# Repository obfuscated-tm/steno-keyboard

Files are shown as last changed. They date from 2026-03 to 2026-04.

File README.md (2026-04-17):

# Owen's Steno Keyboard Mk. 1
The PCB, firmware, casing, as well as the keycaps are all made by myself, from scratch.  
The PCB schematics and design, CAD step files, and firmware are stored within their retrospective folders.

## Screenshots
steno-full  

* On the bottom-most row, the keys on both sides that are furthest away from the center are the number keys.  
* The two double length keys in the middle (one on each side) is the '*' key.
* The other keys follow standard steno layout.
  
steno-keyless  

steno-pcb  

* The decision to have each switch have their own GPIO port is just for ease of assembly and that there was no reason not to do so.  

## Bill of Materials 
- 4 M3 x 12mm screw
- 4 M3 x 0.5mm nut
- 25 Mechanical switches (Cherry MX)
- 1 Raspberry Pi Pico
- 1 PCB
- 1 Micro USB cable
- 3 3D printed 2.5u Steno keycaps (OR 2u standard keycaps)
- 22 3D printed 1.5u Steno keycaps (OR 1u standard keycaps)
- 1 3D printed enclosure (Optional, 3 parts)  
~210g of filament total for 3D printed parts

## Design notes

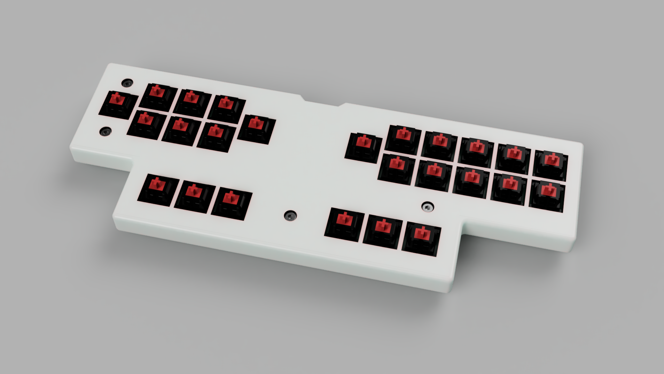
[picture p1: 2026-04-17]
CAD-files/render/steno-keyless.PNG

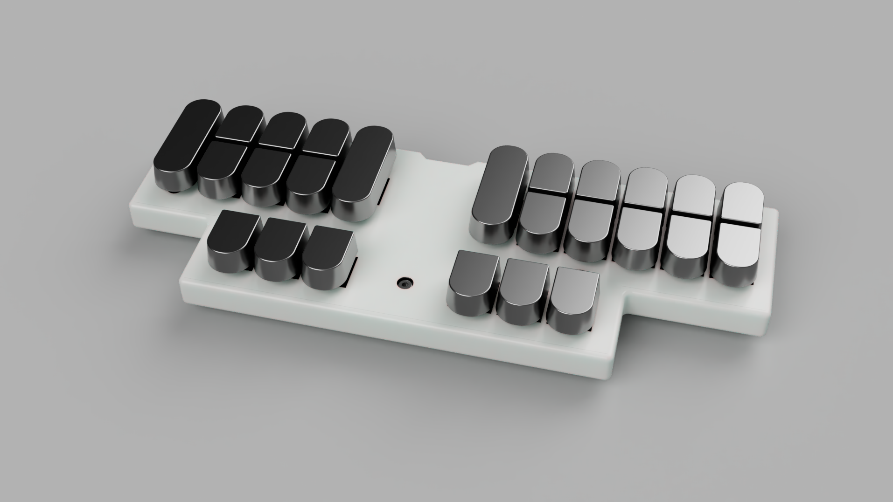
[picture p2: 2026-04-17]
CAD-files/render/steno-full.PNG

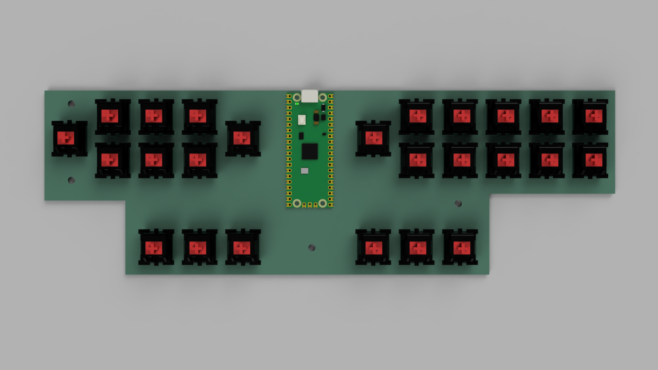
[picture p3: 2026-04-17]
CAD-files/render/steno-pcb.PNG

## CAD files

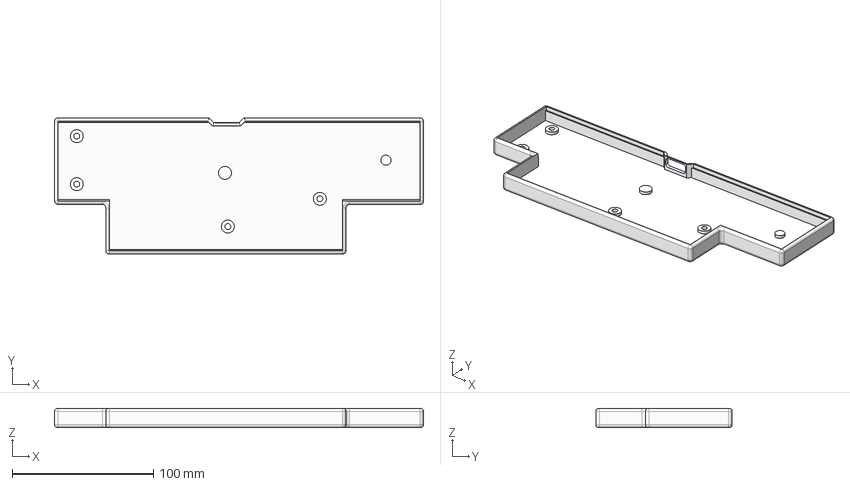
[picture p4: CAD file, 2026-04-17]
CAD-files/housing-body.step
261.4 x 96.6 x 13.5 mm

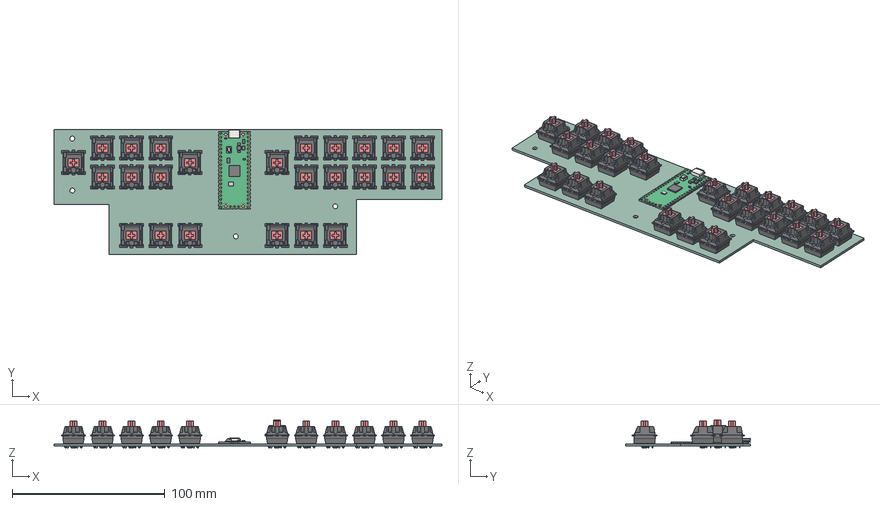
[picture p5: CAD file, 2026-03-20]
steno-pcb/steno-keyboard.step
254.0 x 82.1 x 18.2 mm
RaspberryPi_Pico_Module_KiCad
steno-keyboard_PCB

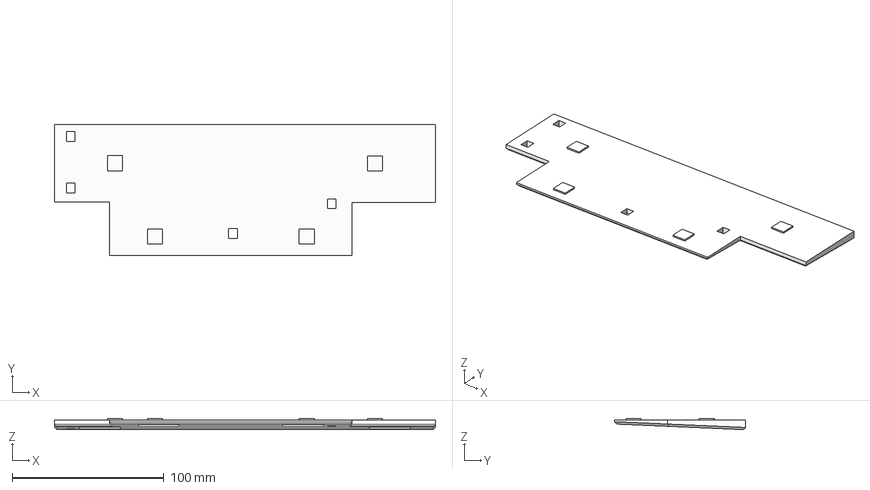
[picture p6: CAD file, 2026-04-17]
CAD-files/housing-base.step
251.4 x 86.6 x 7.44 mm

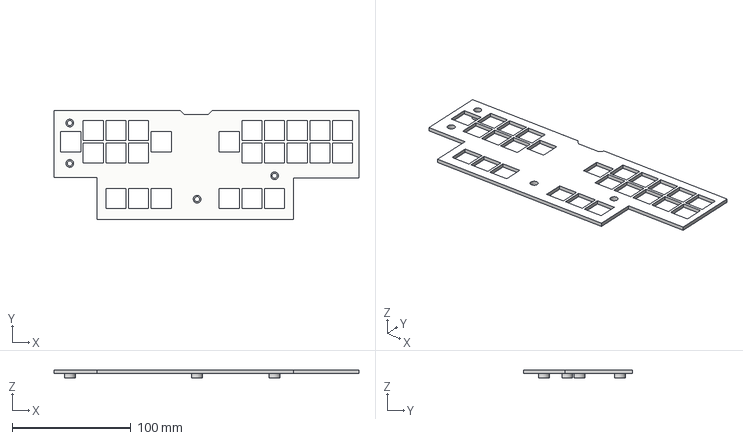
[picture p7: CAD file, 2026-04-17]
CAD-files/top-plate.step
256.4 x 91.6 x 6.83 mm

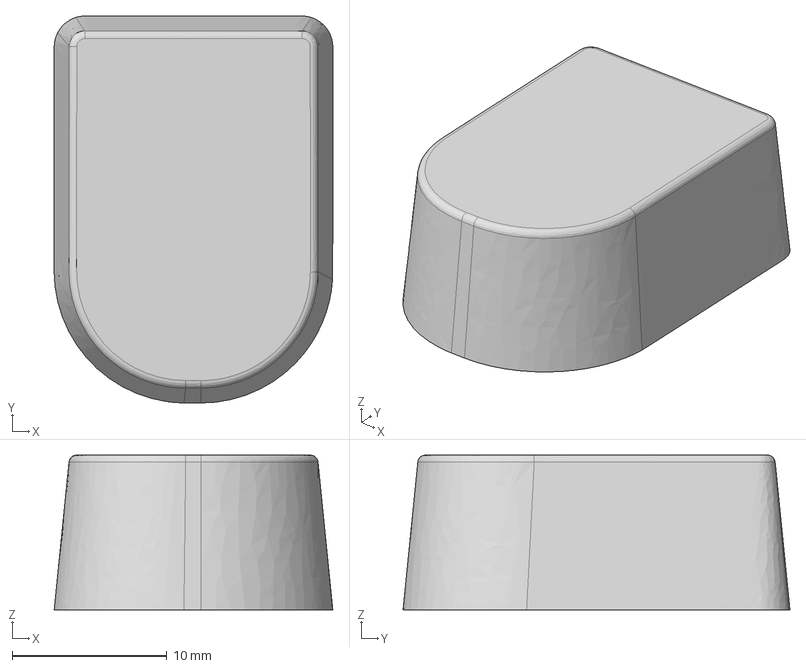
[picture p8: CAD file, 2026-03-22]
CAD-files/steno-keycap-1.5u.step
18.0 x 25.0 x 10.0 mm

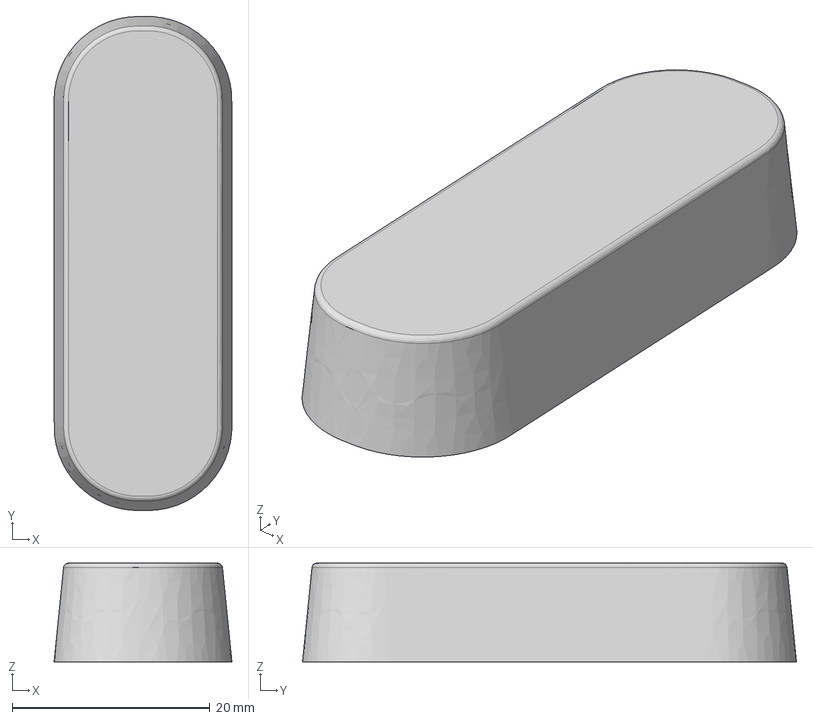
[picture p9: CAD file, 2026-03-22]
CAD-files/steno-keycap-2.5u.step
18.0 x 50.0 x 10.0 mm

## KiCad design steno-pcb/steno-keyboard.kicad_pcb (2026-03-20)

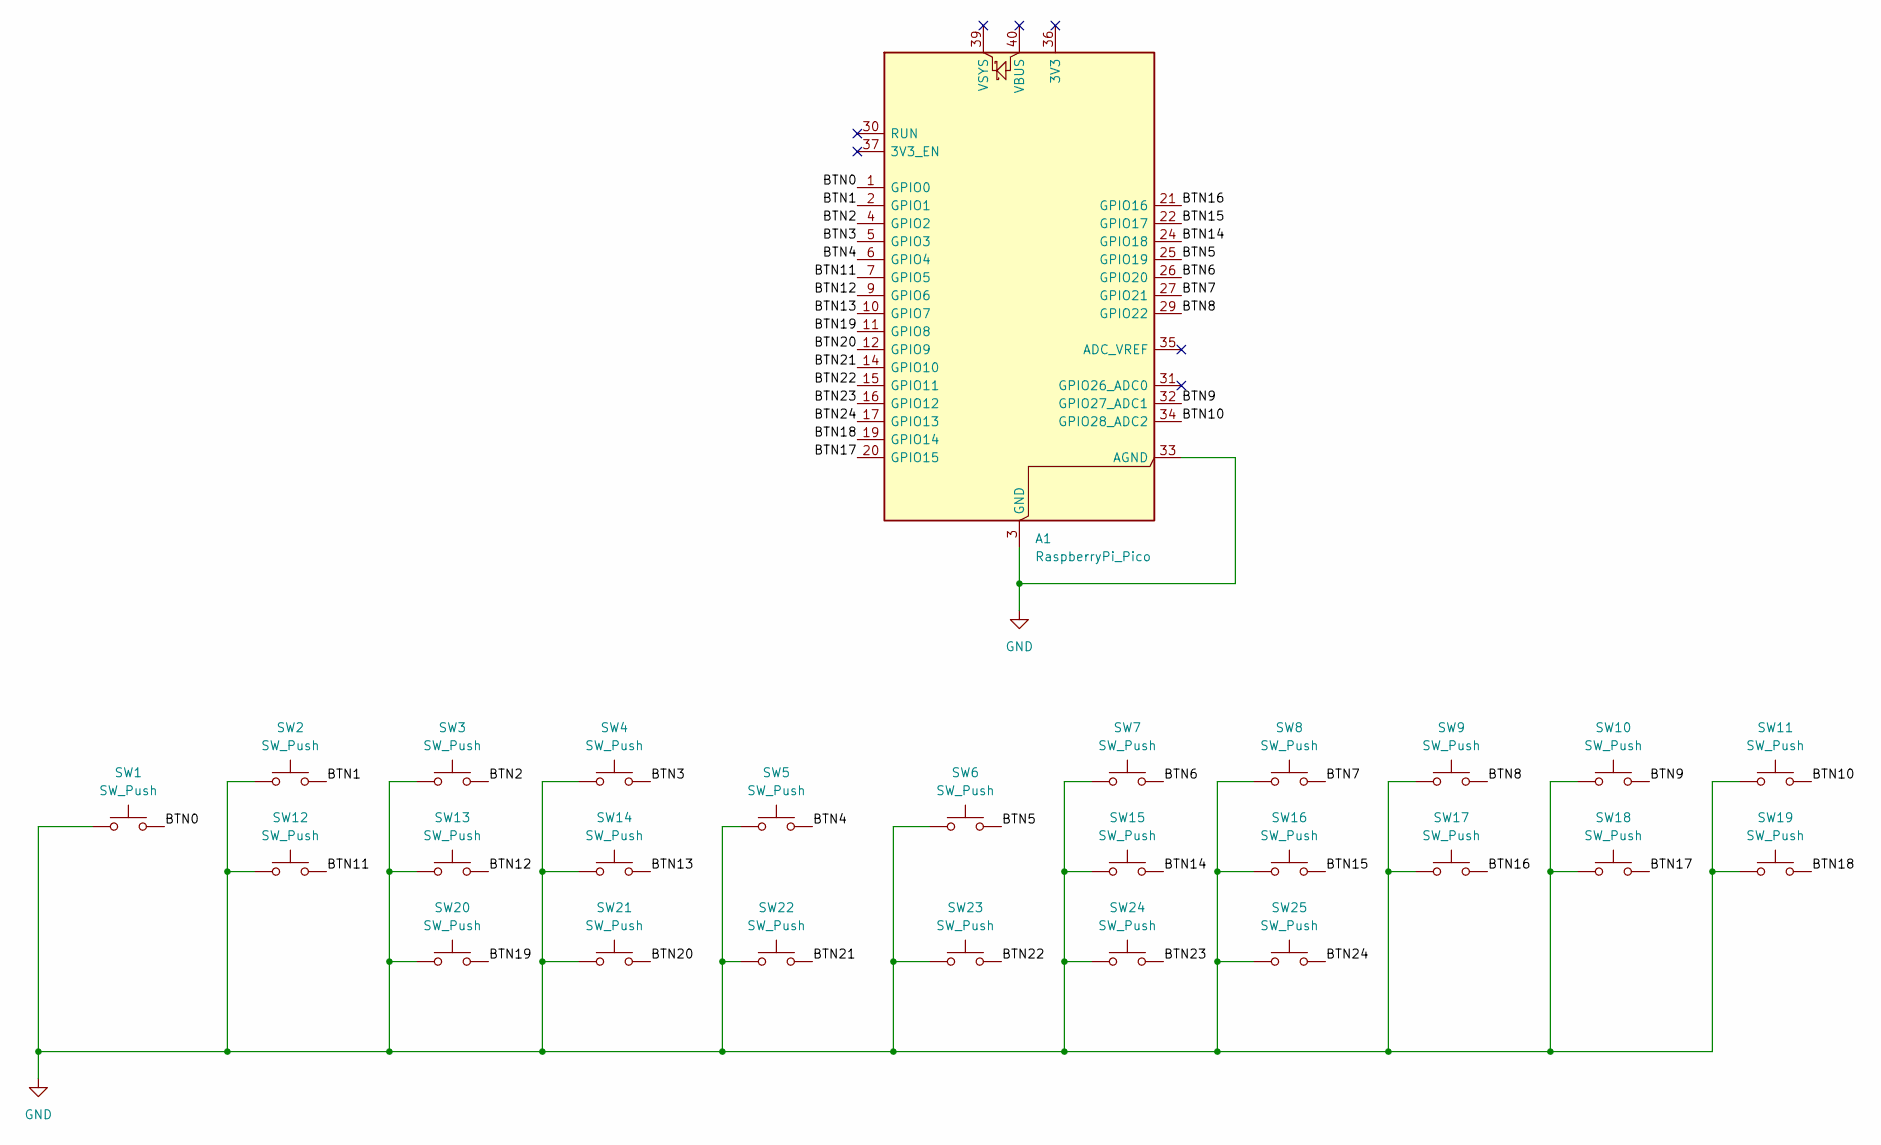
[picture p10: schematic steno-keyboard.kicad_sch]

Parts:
A1: RaspberryPi_Pico; RaspberryPi_Pico_Common_Unspecified
SW1, SW2, SW3, SW4, SW5, SW6, SW7, SW8, SW9, SW10, SW11, SW12, SW13, SW14, SW15, SW16, SW17, SW18, SW19, SW20, SW21, SW22, SW23, SW24, SW25: SW_Push; MX-Solderable-1U

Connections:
/BTN0: A1.1 (GPIO0), SW1.2
/BTN1: A1.2 (GPIO1), SW2.2
/BTN2: A1.4 (GPIO2), SW3.2
/BTN3: A1.5 (GPIO3), SW4.2
/BTN4: A1.6 (GPIO4), SW5.2
/BTN5: A1.25 (GPIO19), SW6.2
/BTN6: A1.26 (GPIO20), SW7.2
/BTN7: A1.27 (GPIO21), SW8.2
/BTN8: A1.29 (GPIO22), SW9.2
/BTN9: A1.32 (GPIO27_ADC1), SW10.2
/BTN10: A1.34 (GPIO28_ADC2), SW11.2
/BTN11: A1.7 (GPIO5), SW12.2
/BTN12: A1.9 (GPIO6), SW13.2
/BTN13: A1.10 (GPIO7), SW14.2
/BTN14: A1.24 (GPIO18), SW15.2
/BTN15: A1.22 (GPIO17), SW16.2
/BTN16: A1.21 (GPIO16), SW17.2
/BTN17: A1.20 (GPIO15), SW18.2
/BTN18: A1.19 (GPIO14), SW19.2
/BTN19: A1.11 (GPIO8), SW20.2
/BTN20: A1.12 (GPIO9), SW21.2
/BTN21: A1.14 (GPIO10), SW22.2
/BTN22: A1.15 (GPIO11), SW23.2
/BTN23: A1.16 (GPIO12), SW24.2
/BTN24: A1.17 (GPIO13), SW25.2
GND: A1.3 (GND), A1.8 (GND), A1.13 (GND), A1.18 (GND), A1.23 (GND), A1.28 (GND), A1.33 (AGND), A1.38 (GND), SW1.1, SW2.1, SW3.1, SW4.1, SW5.1, SW6.1, SW7.1, SW8.1, SW9.1, SW10.1, SW11.1, SW12.1, SW13.1, SW14.1, SW15.1, SW16.1, SW17.1, SW18.1, SW19.1, SW20.1, SW21.1, SW22.1, SW23.1, SW24.1, SW25.1

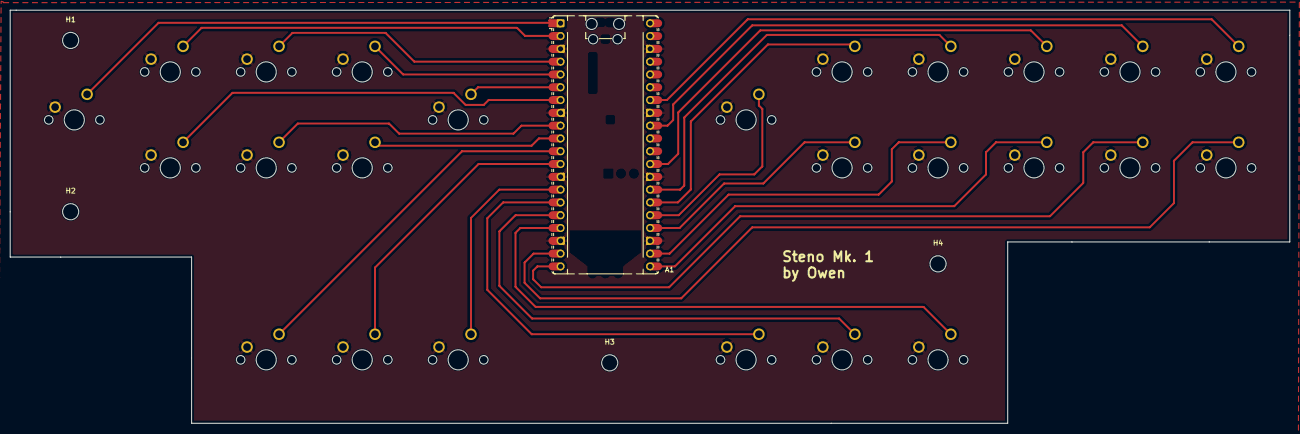
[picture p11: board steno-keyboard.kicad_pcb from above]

Board: 2 copper layers, 254.0 x 82.0 mm, 30 parts (0 on the bottom side), 26 nets.

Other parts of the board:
H1, H2, H3, H4: MountingHole_3.2mm_M3

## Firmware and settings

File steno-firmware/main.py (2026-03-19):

from machine import Pin
import sys
import time

# GPIO pin mapping for each steno key
PINS = {
    "STN_S":    Pin(0, Pin.IN, Pin.PULL_UP), # BTN 0
    "STN_TL":   Pin(1, Pin.IN, Pin.PULL_UP), # BTN 1
    "STN_PL":   Pin(2, Pin.IN, Pin.PULL_UP), # BTN 2
    "STN_HL":   Pin(3, Pin.IN, Pin.PULL_UP), # BTN 3
    "STN_ST1":  Pin(4, Pin.IN, Pin.PULL_UP), # BTN 4
    "STN_KL":   Pin(5, Pin.IN, Pin.PULL_UP), # BTN 11
    "STN_WL":   Pin(6, Pin.IN, Pin.PULL_UP), # BTN 12
    "STN_RL":   Pin(7, Pin.IN, Pin.PULL_UP), # BTN 13
    "NUML":     Pin(8, Pin.IN, Pin.PULL_UP), # BTN 19
    "STN_A":    Pin(9, Pin.IN, Pin.PULL_UP), # BTN 20
    "STN_O":    Pin(10, Pin.IN, Pin.PULL_UP), # BTN 21
    "STN_E":    Pin(11, Pin.IN, Pin.PULL_UP), # BTN 22
    "STN_U":    Pin(12, Pin.IN, Pin.PULL_UP), # BTN 23
    "NUMR":     Pin(13, Pin.IN, Pin.PULL_UP), # BTN 24
    "STN_ZR":   Pin(14, Pin.IN, Pin.PULL_UP), # BTN 18
    "STN_SR":   Pin(15, Pin.IN, Pin.PULL_UP), # BTN 17
    "STN_GR":   Pin(16, Pin.IN, Pin.PULL_UP), # BTN 16
    "STN_BR":   Pin(17, Pin.IN, Pin.PULL_UP), # BTN 15
    "STN_RR":   Pin(18, Pin.IN, Pin.PULL_UP), # BTN 14
    "STN_ST3":  Pin(19, Pin.IN, Pin.PULL_UP), # BTN 5
    "STN_FR":   Pin(20, Pin.IN, Pin.PULL_UP), # BTN 6
    "STN_PR":   Pin(21, Pin.IN, Pin.PULL_UP), # BTN 7
    "STN_LR":   Pin(22, Pin.IN, Pin.PULL_UP), # BTN 8
    "STN_TR":   Pin(27, Pin.IN, Pin.PULL_UP), # BTN 9
    "STN_DR":   Pin(28,Pin.IN, Pin.PULL_UP) # BTN 10
}

DEBOUNCE_MS = 10 # debounce time in milliseconds for the keys
CHORD_WINDOW_MS = 50 # time window in milliseconds to consider keys as part of the same chord
serial = sys.stdout.buffer

def is_pressed(pin):
    return pin.value() == 0

# Return which keys are currently pressed
def read_keys():
    return {name: is_pressed(pin) for name, pin in PINS.items()}

# Debounce logic, counts a key as pressed only if it's still pressed after DEBOUNCE_MS milliseconds
def debounce_read():
    first  = read_keys()
    time.sleep_ms(DEBOUNCE_MS)
    second = read_keys()
    return {name: first[name] and second[name] for name in PINS}

# Adds newly pressed keys into the chord
def merge_chord(accumulated, new_read):
    return {name: accumulated[name] or new_read[name] for name in PINS}

def build_gemini_report(chord):
    """
    Turning a chord into a 6-byte GeminiPR report according to the spec:
    https://docs.qmk.fm/features/stenography

    Byte 0: 1 Fn  #1  #2 #3 #4 #5   #6
    Byte 1: 0 S1- S2- T- K- P- W-   H-
    Byte 2: 0 R-  A-  O- *1 *2 res1 res2
    Byte 3: 0 pwr *3  *4 -E -U -F   -R
    Byte 4: 0 -P  -B  -L -G -T -S   -D
    Byte 5: 0 #7  #8  #9 #A #B #C   -Z
    """
    
    # If either num bar keys are pressed, true
    num = chord["NUML"] or chord["NUMR"]
    
    # If either asterisk keys are pressed, true
    ast = chord["STN_ST1"] or chord["STN_ST3"]

    bits = [
        # Byte 0: 1 Fn #1 #2 #3 #4 #5 #6
        True,  False, num, num, num, num, num, num,
        # Byte 1: 0 S1- S2- T- K- P- W- H-
        False, chord["STN_S"], chord["STN_S"], chord["STN_TL"], chord["STN_KL"], chord["STN_PL"], chord["STN_WL"], chord["STN_HL"],
        # Byte 2: 0 R- A- O- *1 *2 res res
        False, chord["STN_RL"], chord["STN_A"], chord["STN_O"], ast, ast, False, False,
        # Byte 3: 0 pwr *3 *4 -E -U -F -R
        False, False, ast, ast, chord["STN_E"], chord["STN_U"], chord["STN_FR"], chord["STN_RR"],
        # Byte 4: 0 -P -B -L -G -T -S -D
        False, chord["STN_PR"], chord["STN_BR"], chord["STN_LR"], chord["STN_GR"], chord["STN_TR"], chord["STN_SR"], chord["STN_DR"],
        # Byte 5: 0 #7 #8 #9 #A #B #C -Z
        False, num, num, num, num, num, num, chord["STN_ZR"],
    ]

    # Pack every 8 bits into a byte, set MSB for first byte
    result = []
    for b in range(6):
        byte_val = 0
        for i in range(8):
            if bits[b * 8 + i]:
                byte_val |= (1 << (7 - i))
        result.append(byte_val)

    return bytes(result)


def send_chord(chord):
    serial.write(build_gemini_report(chord))





# MAIN LOOP
BLANK_CHORD  = {name: False for name in PINS}

# The chord itself, initally blank, and builds up over time as keys are pressed
accumulated = dict(BLANK_CHORD)
# Timestamp of when the chord started 
chord_start_ms: int | None = None
# Tracks if whether we're mid-chord 
in_chord = False

while True:
    current = debounce_read()
    any_pressed = any(current.values()) # Turns dict into array of keys

    # If any keys are pressed, we're either starting a new chord or continuing an existing chord
    if any_pressed:
        if not in_chord:
            in_chord = True
            chord_start_ms = time.ticks_ms()
        accumulated = merge_chord(accumulated, current)
    else:
        if in_chord:
            assert chord_start_ms is not None # small little safety check
            
            elapsed = time.ticks_diff(time.ticks_ms(), chord_start_ms)
            remaining = CHORD_WINDOW_MS - elapsed
            if remaining > 0:
                time.sleep_ms(remaining)
                accumulated = merge_chord(accumulated, debounce_read())

            send_chord(accumulated)

            # Reset for next chord
            accumulated = dict(BLANK_CHORD)
            chord_start_ms = None
            in_chord = False

    time.sleep_ms(1)

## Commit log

2026-03-12 Update steno-keyboard.kicad_sch
    Changed layout from matrix to direct pin into pico
    [steno-keyboard.kicad_sch]
2026-03-12 Updated PCB and footprints
    [steno-keyboard.kicad_pcb, steno-keyboard.kicad_sch]
2026-03-12 Organized PCB
    [steno-keyboard.kicad_pcb]
2026-03-12 Added traces for PWR
    [steno-keyboard.kicad_pcb]
2026-03-13 Finished PCB and rerouted some wires
    Although the layout is messy, it allows for clean routing of the GPIOs
    [steno-keyboard.kicad_pcb, steno-keyboard.kicad_sch]
2026-03-13 Small fix to connection BTN17
    [steno-keyboard.kicad_pcb]
2026-03-13 Finished PCB
    [steno-keyboard-B_Cu.gbr, steno-keyboard-B_Mask.gbr, steno-keyboard-B_Paste.gbr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]
2026-03-13 Organizing files
    [steno-keyboard-B_Cu.gbr, steno-keyboard-B_Mask.gbr, steno-keyboard-B_Paste.gbr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]
2026-03-13 Updated PCB's labels
    [steno-keyboard-B_Cu.gbr, steno-keyboard-B_Mask.gbr, steno-keyboard-B_Paste.gbr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]
2026-03-13 Updated PCB's labels (KiCad file)
    [steno-keyboard.kicad_pcb]
2026-03-15 Started firmware for board in circuit python
    [steno-keyboard-B_Cu.gbr, steno-keyboard-B_Mask.gbr, steno-keyboard-B_Paste.gbr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]
2026-03-15 Uses micropy instead of circuit py
    This is treated as a serial device than an HID
2026-03-19 Update GPIO pins and started PCB'sCAD
    Made the pin numbers the physical pins instead of GPIO.
    [steno-keyboard.step]
2026-03-20 Updated 3D model of PCB
    Removed placeholder keycaps and added keyboard switches to all spots (makes it easier to create the models for the keycaps and housing).
    [steno-keyboard.kicad_pcb, steno-keyboard.step]
2026-03-21 Added keycap STEP files
    [steno-keycap-1.5u.step, steno-keycap-2.5u.step]
2026-03-22 Reinforced keycap pin structure
    [steno-keycap-1.5u.step, steno-keycap-2.5u.step]
2026-03-22 Slight edit to the pin structure to the 1.5u keycap
    Bumped up the pins' base
    [steno-keycap-1.5u.step]
2026-04-17 Added keyboard's body CAD files
    [housing-base.step, housing-body.step, top-plate.step]
2026-04-17 Update README with project details and images
    Added additional details about the project, including screenshots and a bill of materials.
2026-04-17 Add Micro USB cable to components list
